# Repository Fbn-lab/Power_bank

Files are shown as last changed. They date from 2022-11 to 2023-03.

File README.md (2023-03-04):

(语言 language) : [CN](https://github.com/fBn0523/Power_bank/blob/main/README.md)|[EN](https://github.com/fBn0523/Power_bank/blob/main/README_EN.md)
# Power_bank
创意设计可乐形状的充电宝\
体积:65直径x116高(mm)\
方案: bm3451电池保护芯片+ip2368充电宝soc(5串18650带均衡)
# 参数

     快充协议:   FCP AFC SCP DPR Try.SRC PD3 QC2 QC3 QC3+(具体以手册为准)
     电压挡位:   5V 9V 12V 15V 20V
     输入:        最大60w 20V3A (双导热管)
                  最大40w 20V2A (无导热管)
     输出:         60W最大20V 3A
     充电指示灯:     (具体根据自己选用的指示灯颜色)
                          放电:                     充电:
                          白 100%~66%               充满 白
                          黄白 66%~33%              100%~66% 白闪
                          黄 小于33%                66%~33%  黄白闪
                          黄闪后结束输出 0%          33%~0%黄闪

# 特性
      1. 双铜管散热
      2. 保护板控制板叠层设计紧凑内部空间
      3. 可拆卸锂电池仓.方便更换电芯
      4. 60W快充,平衡容量和充电速度.1时20分即可充满
# 制造可行性

      1. 所有零件均可以使用fdm  3d打印制造
      2. 优化电路板减少手工焊接短路风险
      3. 开源文件包含pcb焊接示意图,方便查看每个零件需要焊接的位置
      4. 使用5节亿纬锂能3300mah 18650电芯.整体造价100(人民币)左右
      5. 外壳需要使用两个330ml可口可乐罐,切割工具需自备
# 图片
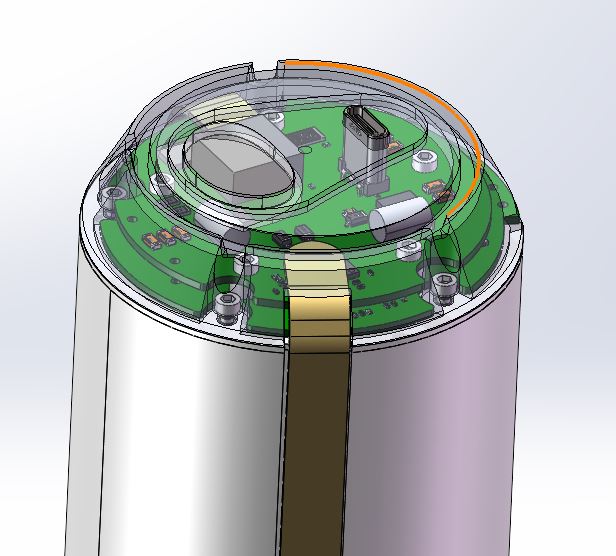
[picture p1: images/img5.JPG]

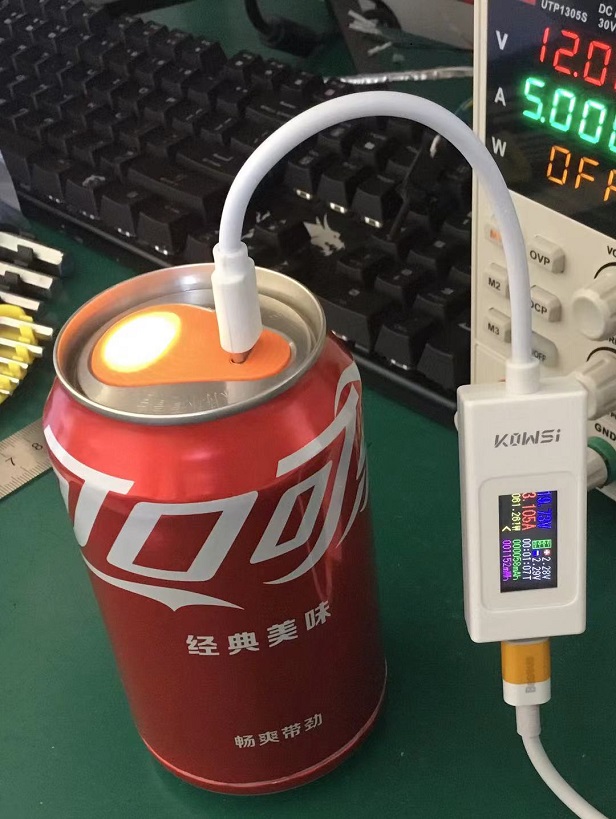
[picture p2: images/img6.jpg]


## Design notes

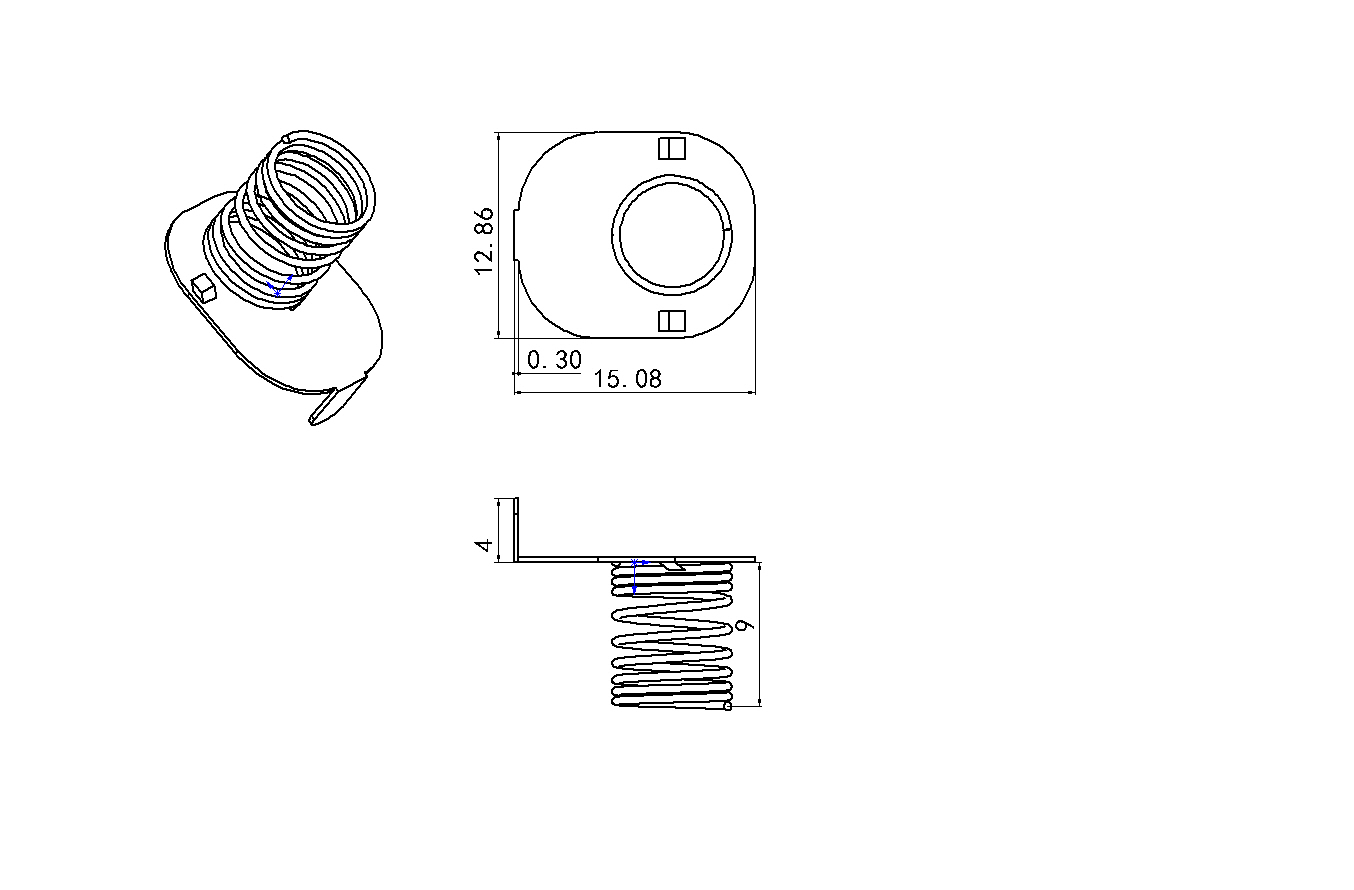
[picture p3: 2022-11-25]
images/18650电极片负极_弹簧.JPG

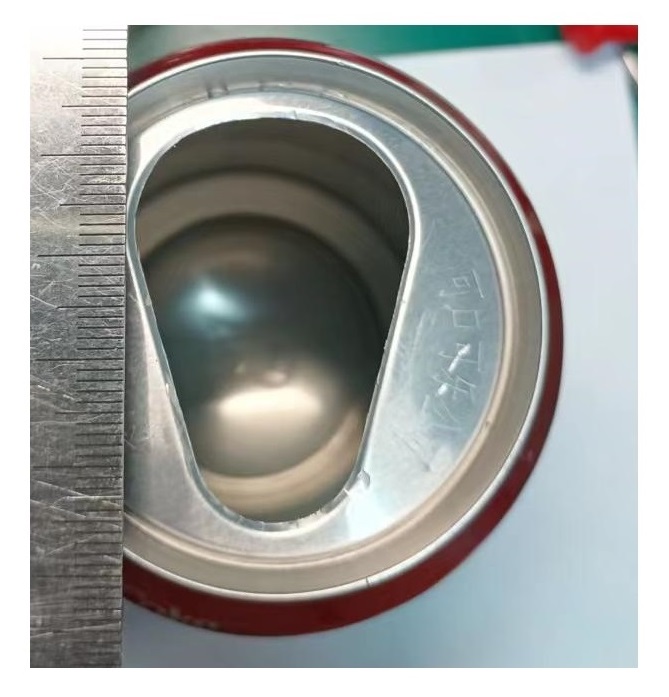
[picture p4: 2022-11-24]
images/切割示意图.jpg

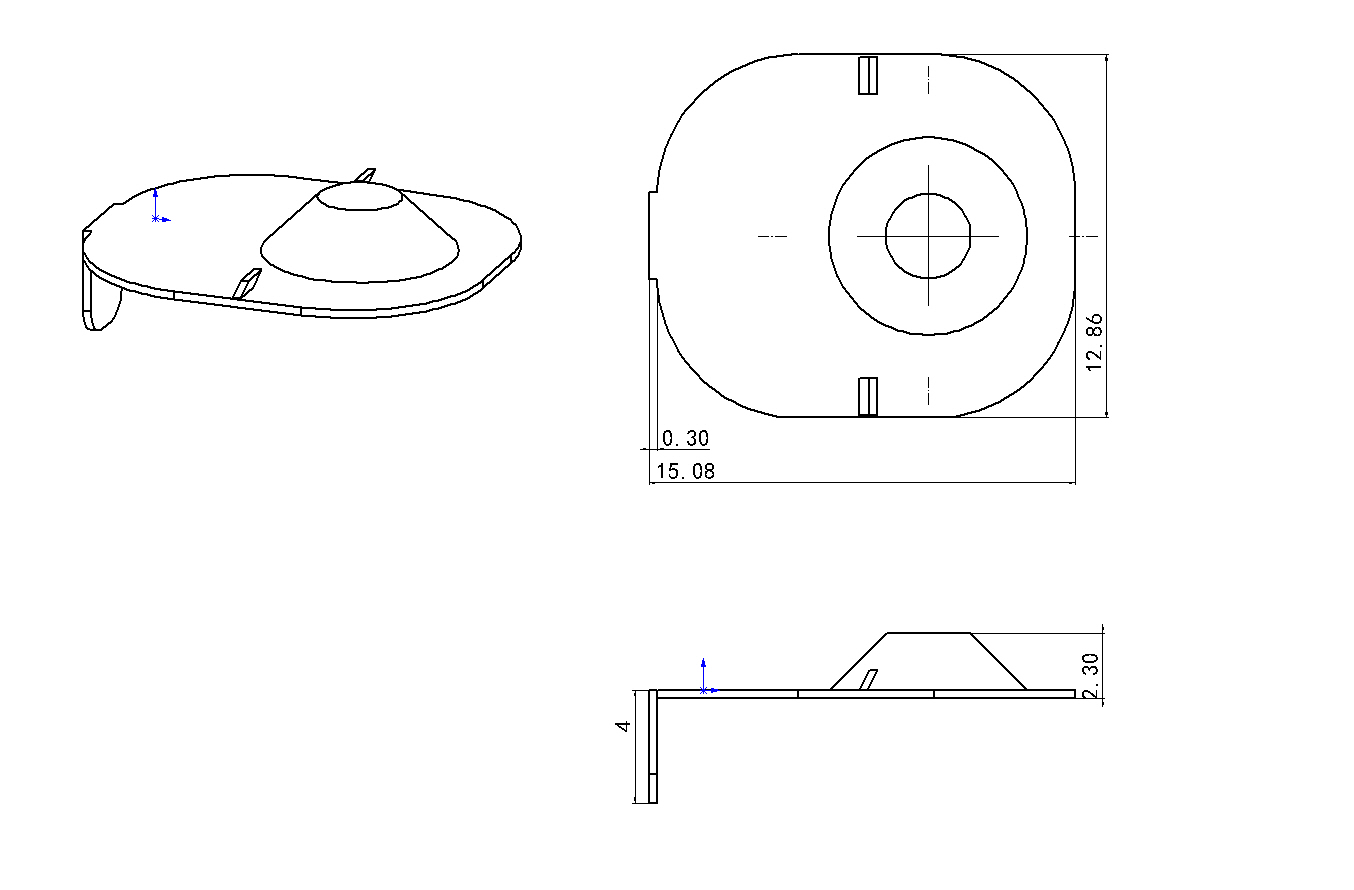
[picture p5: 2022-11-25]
images/18650电极片正极_凸点.JPG

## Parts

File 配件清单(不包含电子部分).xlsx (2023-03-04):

名称 | 数量
M2x5杯头内六角螺丝 | 13
M2x8杯头内六角螺丝 | 5
M3x5杯头内六角螺丝 | 5
热熔铜螺母M2x3x3.2 | 18 | 高度3~5mm均可.越长越结实
热熔铜螺母M3x3x4.2 | 5
电极片负极 | 5 | 详细参数见\Power_bank\images
电极片正极 | 5 | 详细参数见\Power_bank\images
导热垫片10x10x1.5 | 1
导热管 | 2 | 宽9 长8 厚1(mm)
铜片 | 1 | 长15 宽 5 厚0.3 (mm)

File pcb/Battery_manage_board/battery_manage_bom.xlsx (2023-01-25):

Comment | Description | Designator | Footprint | Quantity
BATTERY_18650- | 18650电池片 | B2, B4, B6, B8, B10 | BATTERY_18650- | 5
10uF | 无极性电容 | C1 | 0805C | 1
1uF | 无极性电容 | C2, C3, C4, C9, C10 | 0402C | 5
100nF | 无极性电容 | C5, C6, C7, C8 | 0402C | 4
NTC_100K_B3950 | 无极性电容 | C11 | 1210C | 1
BM3451TJDC | 电池管理芯片 | IC1 | SOP65P640X120-28N | 1
2302 | MOSFET (N-Channel) | Q1, Q2, Q3, Q4, Q5 | SOT95P280X125-3N | 5
KNY3403 | MOSFET (N-Channel) | Q6, Q7 | DFN5x6 | 2
1K | 电阻 | R1, R2, R5, R10, R13, R20 | 0402R | 6
47R | 电阻 | R3, R6, R11, R15, R22 | 1812R | 5
4.7MR | 电阻 | R4, R8, R12, R19, R23 | 0402R | 5
1MR | 电阻 | R7, R9 | 0402R | 2
92K | 电阻 | R14 | 0402R | 1
220K | 电阻 | R16 | 0402R | 1
2K | 电阻 | R17 | 0402R | 1
10MR | 电阻 | R18, R24 | 0805R | 2
5mR | 合金检流电阻 | R21 | 2512R | 1

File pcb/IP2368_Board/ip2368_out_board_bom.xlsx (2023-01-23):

Comment | Description | Designator | Footprint | Quantity
22uF/25V | 无极性电容 | C1, C11, C12, C13, C15, C16, C17 | 1206C | 7 | C12891
1uF/25V | 无极性电容 | C2, C6, C7, C20 | 0402C | 4
10uF/50V | 无极性电容 | C3 | 0805C | 1
2.2uF/16V | 无极性电容 | C4, C5 | 0402C | 2
100nF/50V | 无极性电容 | C8, C9, C10, C18 | 0402C | 4
100uF/25V | 固态电解电容 | C14, C19 | SMD_2x5x8 | 2 | 直径5长度8,引脚间距2(mm)
LED | 双色LED(金/白) | D1 | SMD2835 | 1
SMAJ30CAYK | TVS二极管 30V | D5, D6, D7 | SOD-123 | 3
IP2368 |  | IC2 | QFN50P700X700X90-49N-D | 1
10uH | 功率电感 | L1 | SMD_12x12x6(长宽高) | 1 | C526024
RU30J30M | 双 NMOS(半桥) | Q1, Q2 | PDFN5x6 | 2 | C2803361
KNY3403 | MOSFET (N-Channel) | Q3 | DFN5x6 | 1 | C2839428
2K | 电阻 | R1, R7 | 0402R | 2
100R | 电阻 | R2, R3 | 0402R | 2
10K | 电阻 | R4, R6 | 0402R | 2
15K | 电阻 | R5 | 0402R | 1
18K | 电阻 | R8 | 0402R | 1
10R | 电阻 | R9, R10 | 0402R | 2
0.01R | 电阻 | R11, R13 | 1206R | 2
0.005R | 电阻 | R12 | 2512R | 1
2R | 电阻 | R14, R15 | 0402R | 2
1K | 电阻 | R16 | 0402R | 1
USB_C | 连接器 | U1 | USB-C 立贴 | 1 | 14PIN 立贴 立创商品编号C2843970

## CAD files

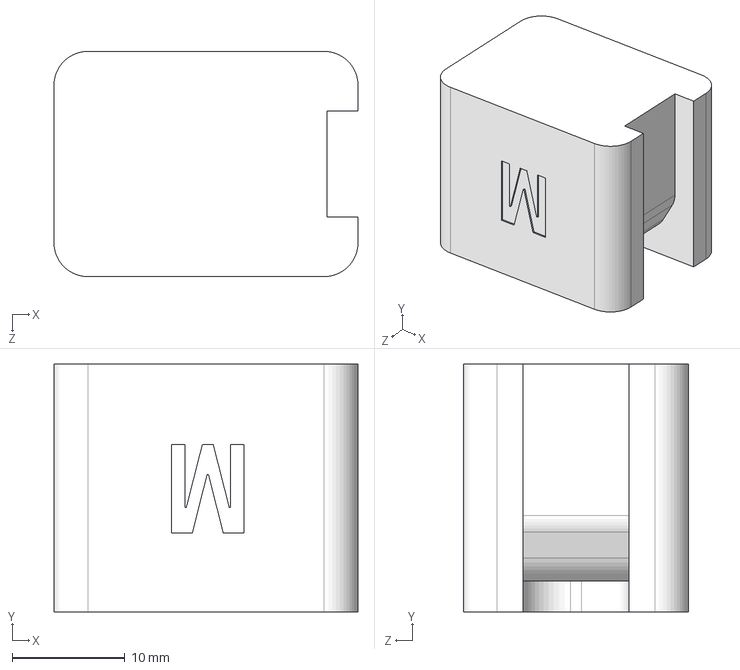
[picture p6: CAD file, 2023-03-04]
model/STEP/mos铜管模具.STEP
27.0 x 22.0 x 20.0 mm

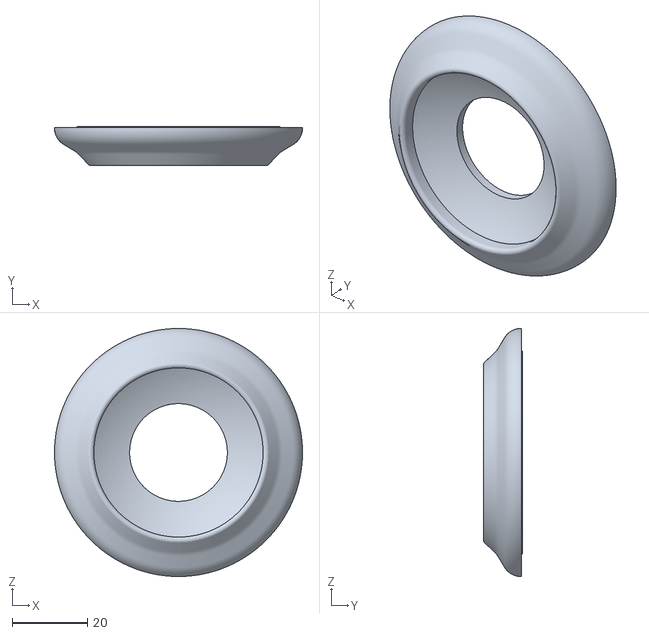
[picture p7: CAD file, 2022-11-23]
model/STL/可乐罐底支架_百事可乐.STL
66.0 x 10.4 x 66.0

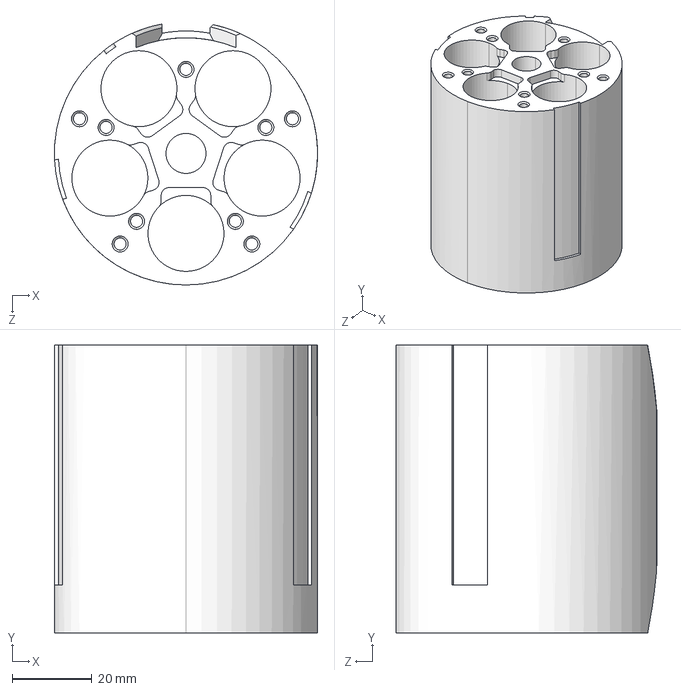
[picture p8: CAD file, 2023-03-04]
model/STEP/电池仓主体.STEP
65.8 x 72.0 x 65.2 mm

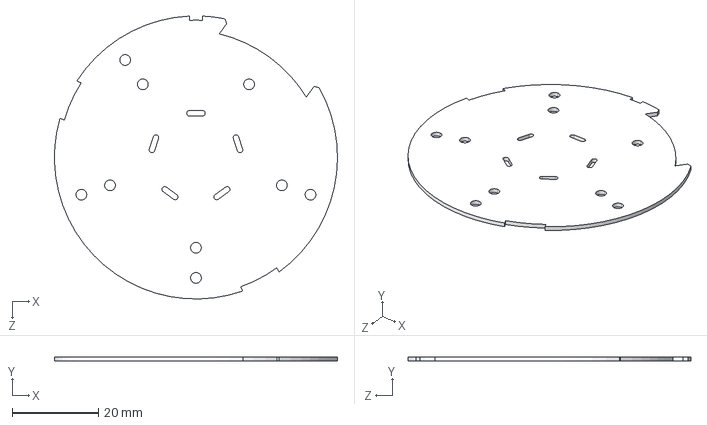
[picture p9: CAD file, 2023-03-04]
model/STEP/电池仓保护板_隔离板.STEP
65.8 x 1.00 x 65.8 mm

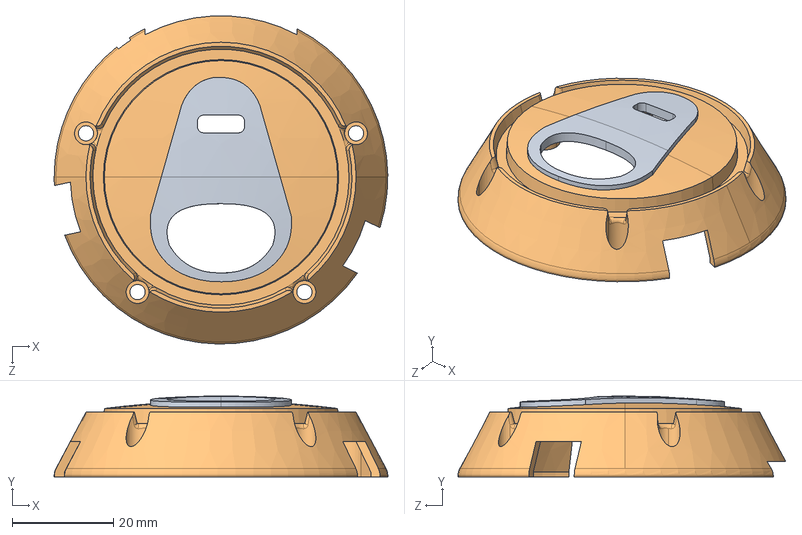
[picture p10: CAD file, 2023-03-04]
model/STEP/电池仓上盖.STEP
65.8 x 16.0 x 64.7 mm

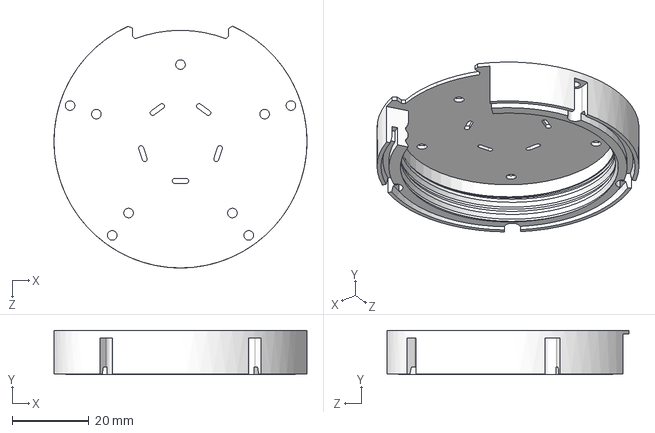
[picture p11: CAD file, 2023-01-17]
model/STEP/电池仓下盖.STEP
65.8 x 11.5 x 62.9 mm

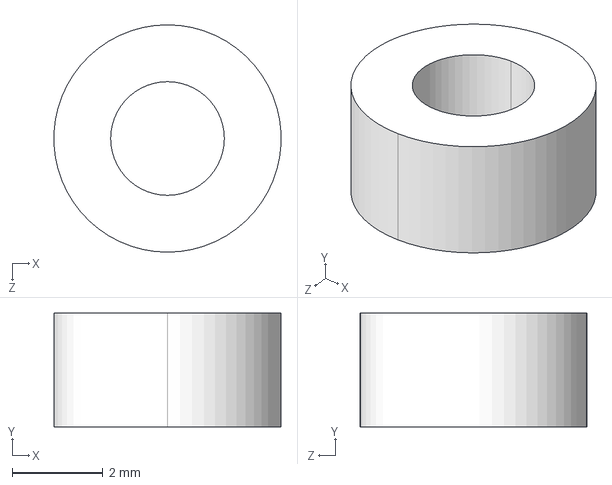
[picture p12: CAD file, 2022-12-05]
model/STEP/保护板_充电板支架.STEP
4.99 x 2.50 x 5.00 mm

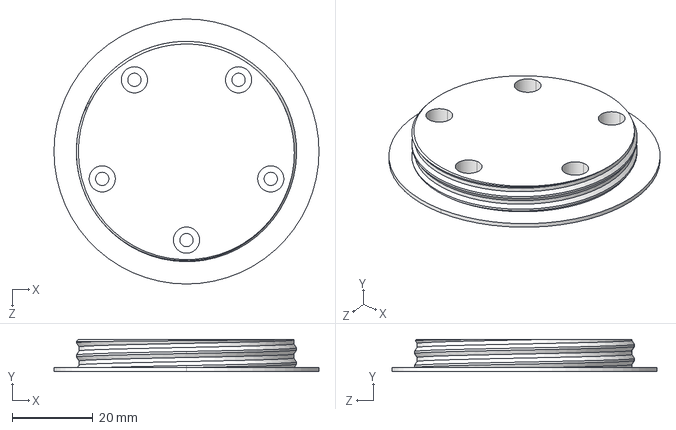
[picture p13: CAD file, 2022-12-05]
model/STEP/可乐罐支架上罐体压合_凸螺纹.STEP
65.8 x 8.00 x 65.8 mm

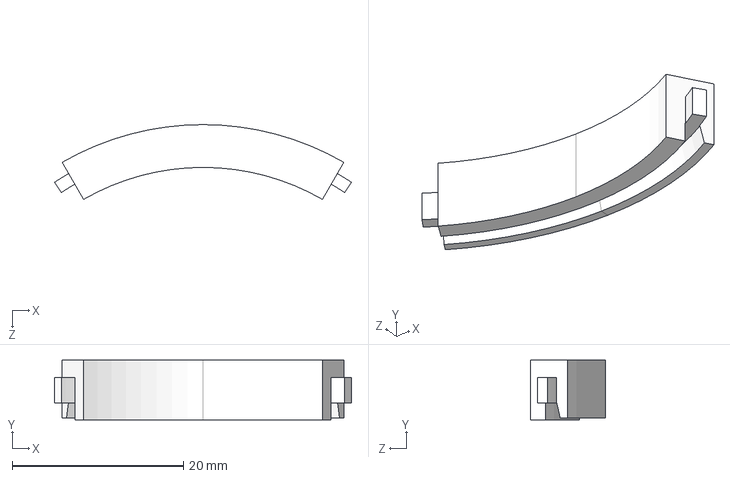
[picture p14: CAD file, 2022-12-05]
model/STEP/电池仓下盖缺口补充.STEP
34.7 x 7.00 x 8.74 mm

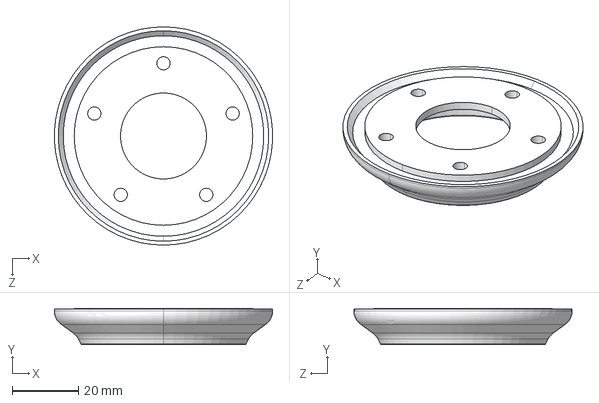
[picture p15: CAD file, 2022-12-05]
model/STEP/可乐罐底支架_可口可乐.STEP
65.9 x 10.9 x 66.0 mm

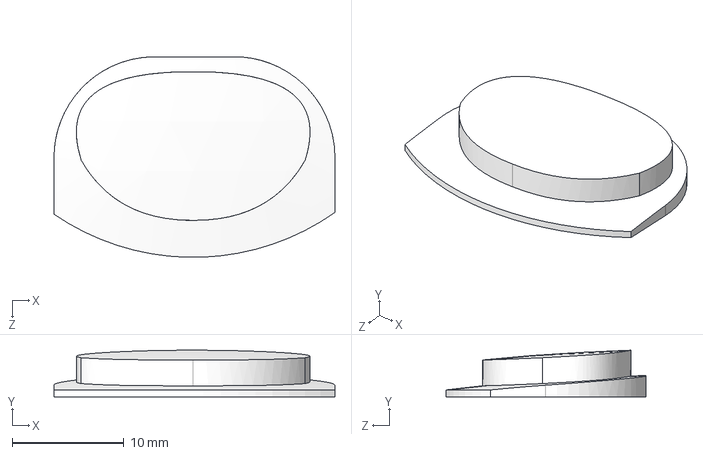
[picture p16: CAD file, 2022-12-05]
model/STEP/充电板指示灯.STEP
25.1 x 4.17 x 17.9 mm

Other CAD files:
model/STEP/soc铜管模具.STEP
model/STL/mos铜管模具.STL
model/STL/soc铜管模具.STL
model/STL/保护板_充电板支架.STL
model/STL/充电板指示灯.STL
model/STL/可乐罐底支架_可口可乐.STL
model/STL/可乐罐支架上罐体压合_凸螺纹.STL
model/STL/电池仓上盖.STL
model/STL/电池仓下盖.STL
model/STL/电池仓下盖缺口补充.STL
model/STL/电池仓主体.STL
model/STL/电池仓保护板_隔离板.STL

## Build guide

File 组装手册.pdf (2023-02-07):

# 充电宝制造教程

目录:

1: 3D 打印注意事项
2: pcb 制造注意事项
3:组装步骤:
3.1:电池仓主体热熔螺母安装
3.2:保护板电极片焊接
3.3:上半部分总成
3.4:热敏电阻安装
3.5:底部支架热熔螺母安装

## 3.6:支架总成

3.7:正极电极片焊接
3.8:电池仓总成
3.9:指示灯安装

## 4.0:上盖总成

4:导热管安装:

## 4.1 mos 导热管弯管 4.2 soc 导热管弯管

5 外壳切割:

## 5.0:罐 A 下底切割 5.1:罐 B 下底切割 5.2:罐 B 上切口

6:建议
附录:

## 1.pcb 配件表 2.pcb 焊接指导

3.机械配件表

## 1: 3D 打印制造事项

## 模型目录(\Power_bank\model\STL)

建议印刷材料 ABS 0.4 喷嘴 壁厚 4 ,层高 0.12, 顶底 5

## 模型:(有条件的都上防火材料吧)

电池仓主体x1 | 务必 ABS!! 耐热 70 度!!热敏电阻开口,底部斜边加支撑
电池仓下盖 x1
电池仓下盖缺口补充 x1
电池仓上盖 x1 | 盖口向下打印,风冷开满
充电板指示灯 x1 | 透光白色
保护板充电板支架 x5 | 务必 ABS(否则模型塌陷导致 pcb 短路)
电池仓保护板_隔离板 x1 | 可以选择激光切割或者 pcb 方式加工硬质板材
可乐罐底支架_可口可乐(可选百事可乐)x1
可乐罐支架上罐体压合_凸螺纹 x1

## 弯管模具 mos x1 弯管模具 soc x1

## 2: pcb 制造注意事项

充电电流设置电阻(R15) 建议 2K(2A) 兼顾快充和电池寿命 建议充放电控制板和电池保护板之间贴导热垫

## 3: 组装步骤:

3.1 电池仓主体热熔螺母安装
1. 电池仓主体.STL | x1
2. 2.热熔螺母 M2 (长度 3~5) | x18

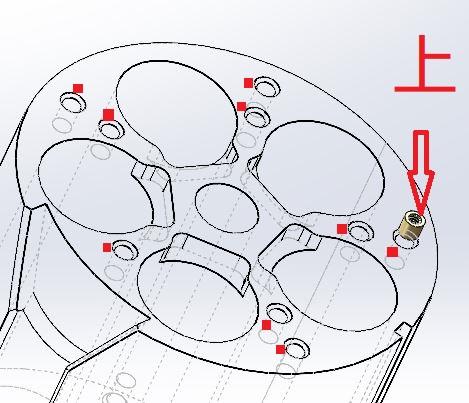
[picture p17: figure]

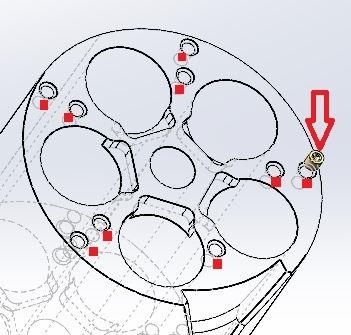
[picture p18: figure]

3.2 保护板电极片焊接

## Pcb(Battery_manage_board) x1

电池仓保护板_隔离板.STL | x1
18650 电极片负极_弹簧 | x5

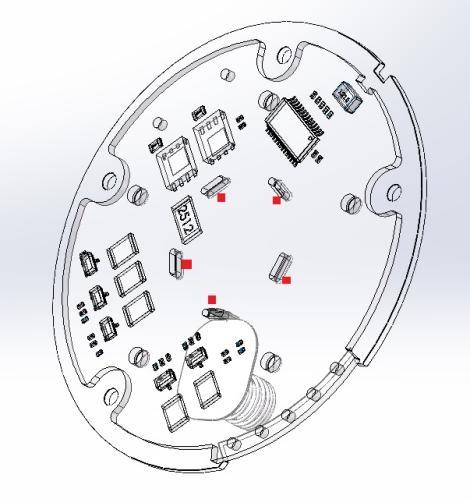
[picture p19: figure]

3.3 上半部分总成
M2x8 | x5
保护板_充电板支架.STL | x5
Pcb(IP2368_Board) | x1
导热硅胶垫 | x1

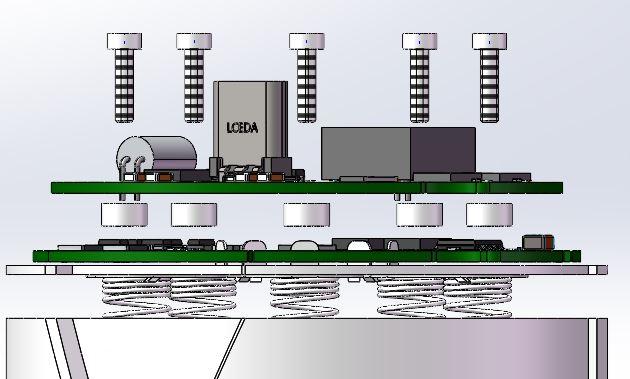
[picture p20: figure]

3.4 热敏电阻安装
NTC100K B3950 | x1

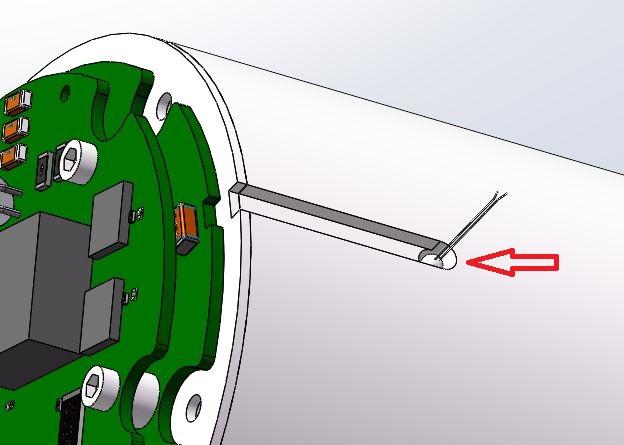
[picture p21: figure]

3.5 底部支架热熔螺母安装
可乐罐底支架_可口可乐.STL | x1
热熔螺母 M3 高 3mm | x5

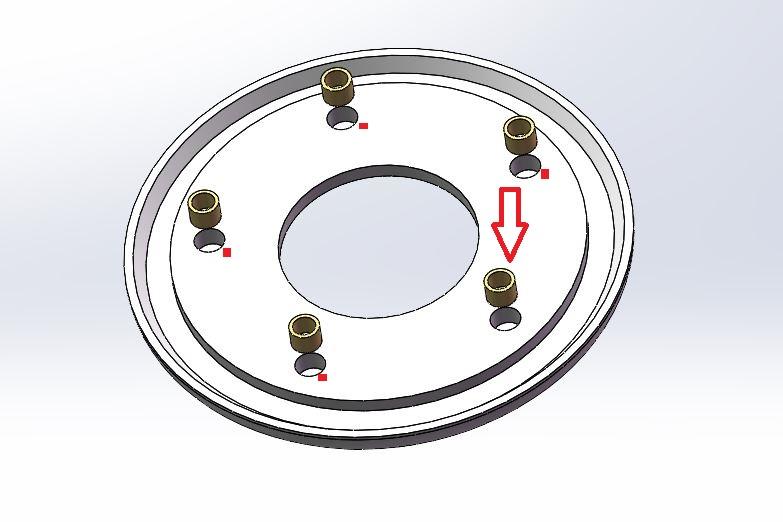
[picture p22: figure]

3.6 支架总成
可乐罐支架上罐体压合_凸螺纹.STL | x1
M3x5 | x5
可乐罐下底切割 | x1

切割底盖卡入槽中,并压紧螺纹支架

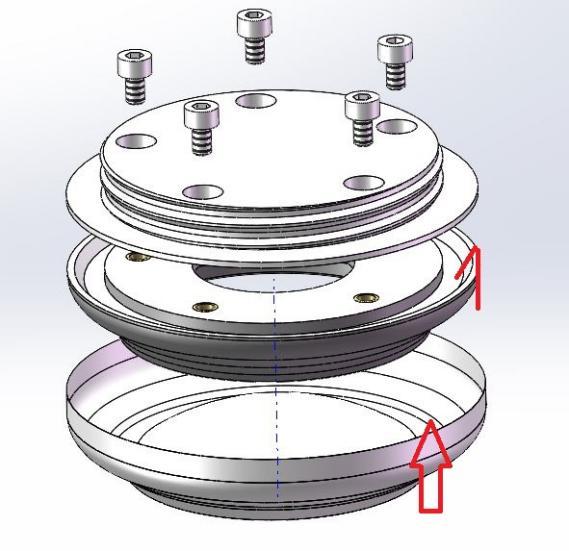
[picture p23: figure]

3.7 正极电极片焊接
电池仓下盖.STL | x1
Pcb(battery_bottom_board) | x1
18650 电极片正极_凸点 | x5

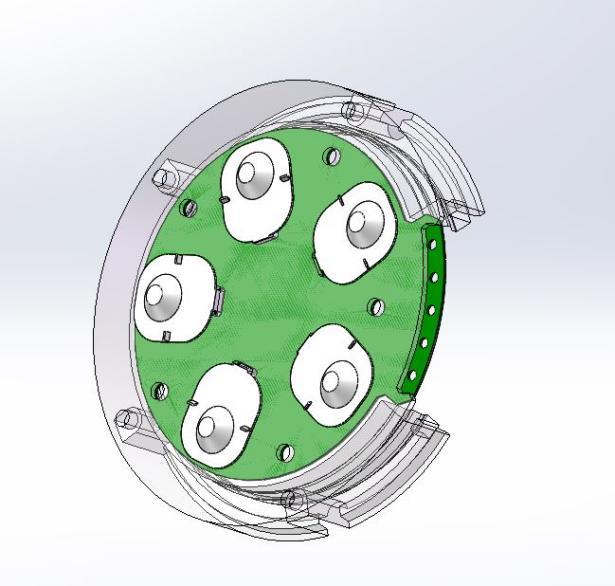
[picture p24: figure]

3.8 电池仓总成
18650 电池 | x5
M2x5 | 9

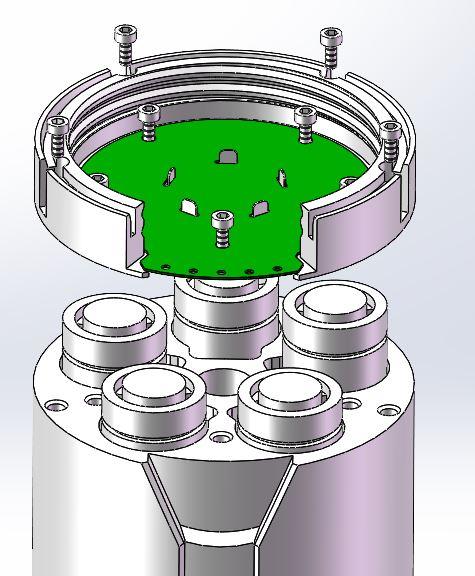
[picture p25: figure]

3.9 指示灯安装
充电板指示灯.STL | x1
电池仓上盖.STL | x1
需要胶水固定

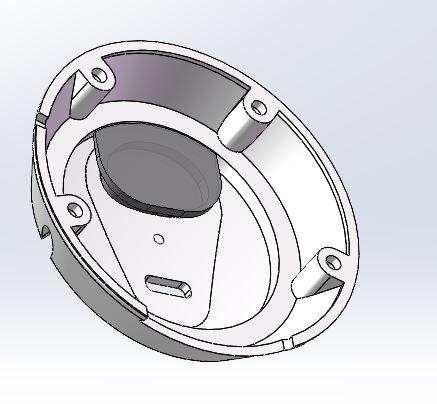
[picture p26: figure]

4.0 | 上盖总成
M2x5 | x4

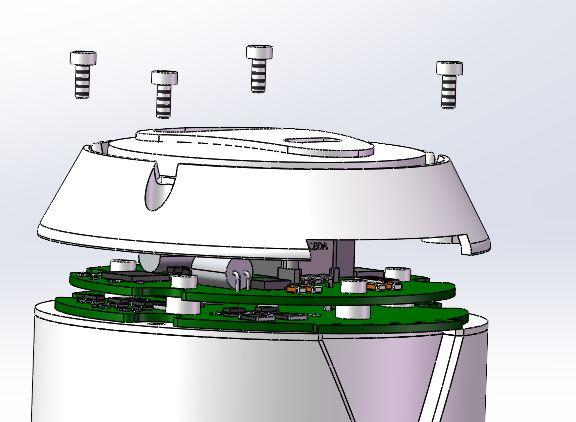
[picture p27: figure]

4: 导热管安装
材料准备
8x9x1(长宽高)(mm)导热管 | x2
弯管模具 mos | x1
弯管模具 soc | x1
导热硅脂
导热胶
4.1 mos 导热管弯管 | 4.2 soc 导热管弯管

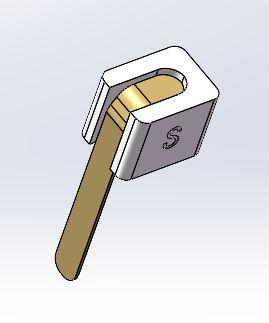
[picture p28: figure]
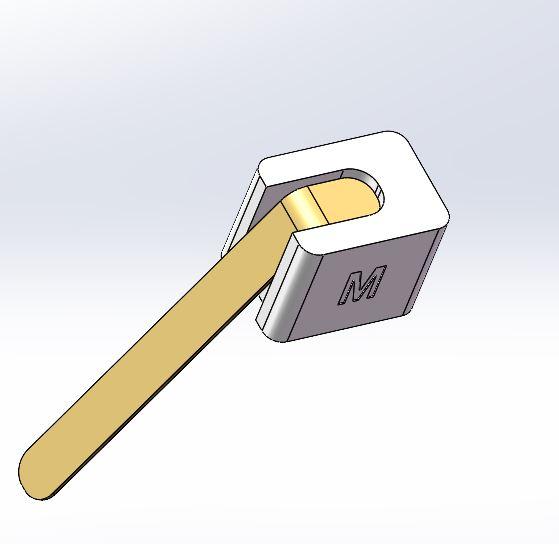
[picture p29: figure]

## 5 材料准备

可口可乐罐 | x2

5.0 罐 A 下底切割

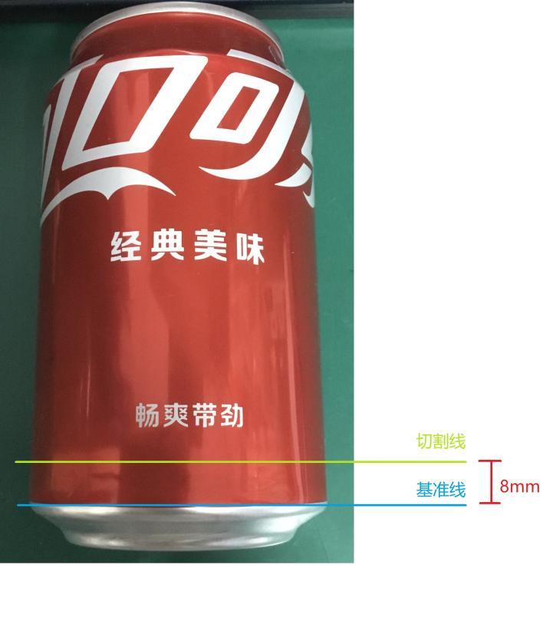
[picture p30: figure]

5.1 罐 B 下底切割

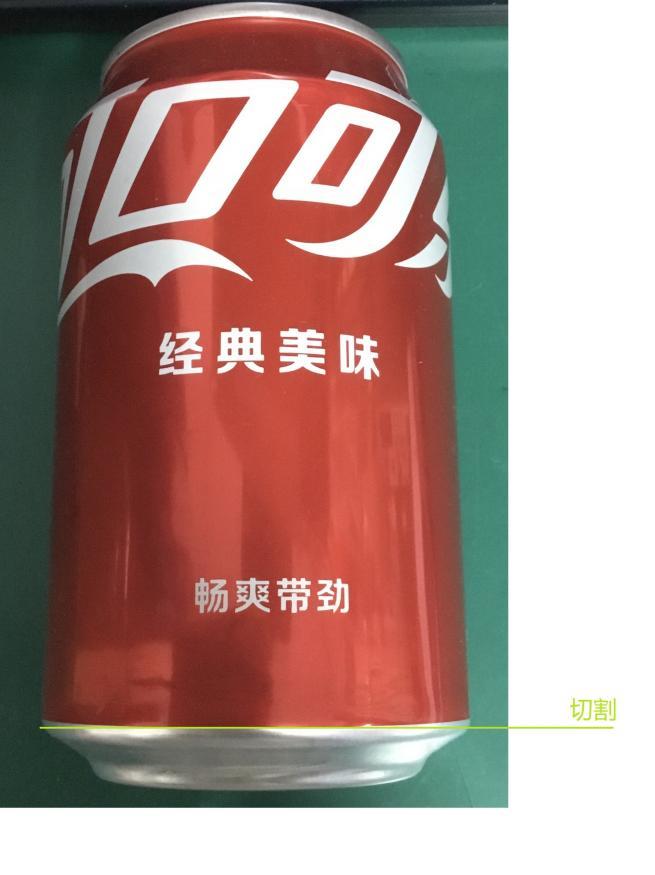
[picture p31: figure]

## 5.2 罐 B 上切口

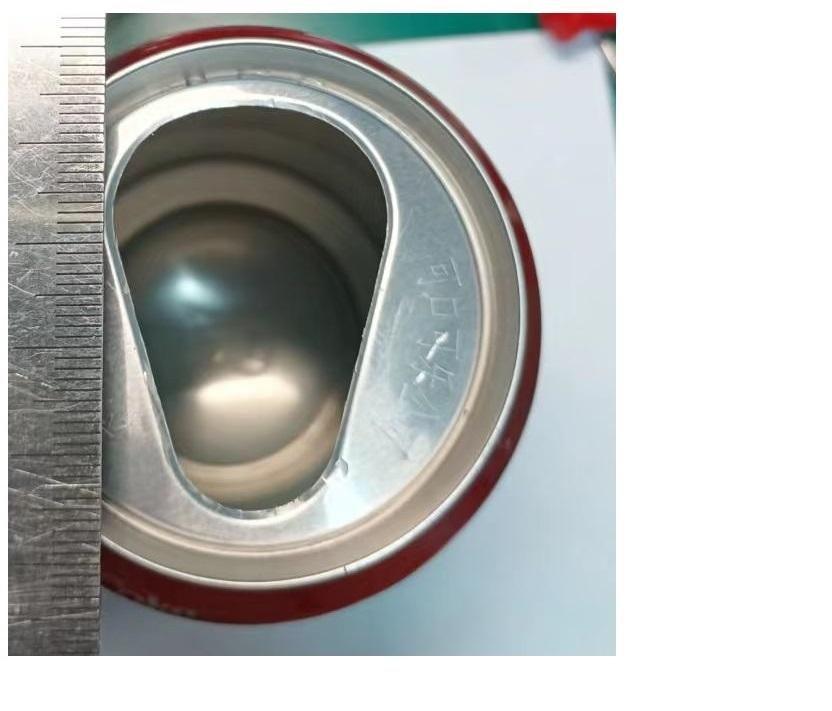
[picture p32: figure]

附录:

## 充电板(\Power_bank\pcb\IP2368_Board\IP2368_Board_bom.xlsx)

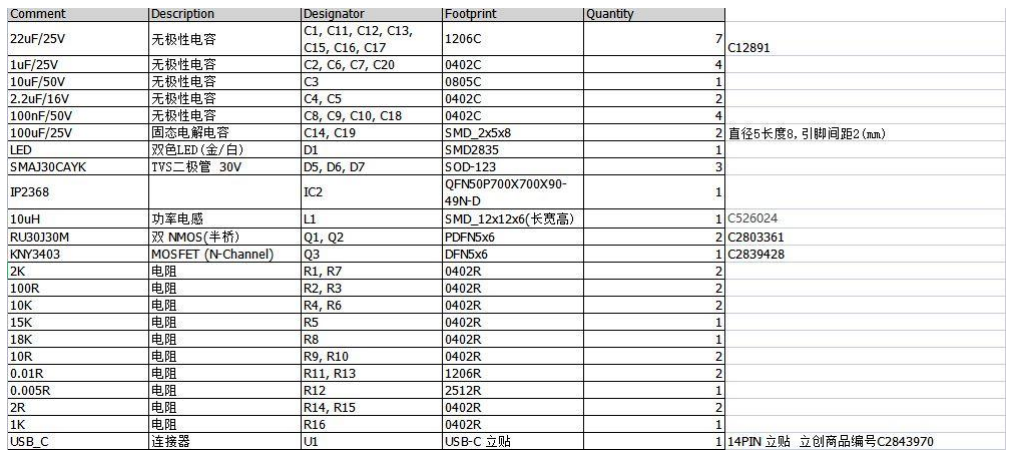
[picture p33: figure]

## pcb 焊接指导(\Power_bank\pcb\IP2368_Board\IP2368_Board_bom.html)

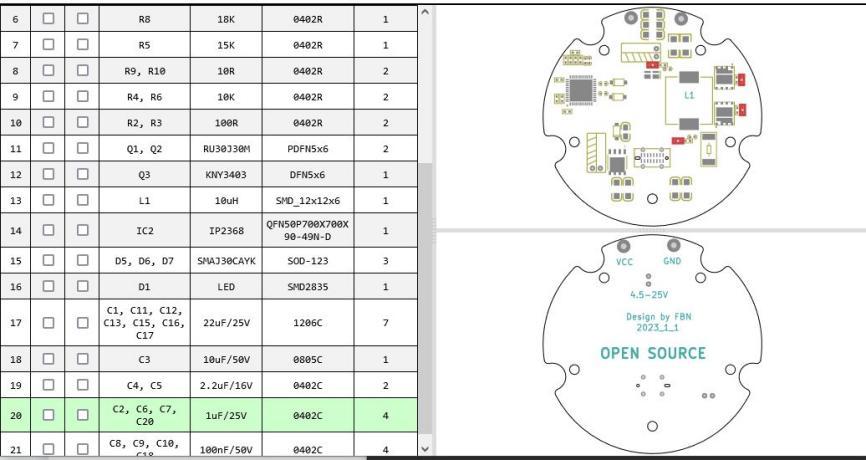
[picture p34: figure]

电池保护板

## (\Power_bank\pcb\Battery_manage_board\Battery_manage_board_bom.xlsx)

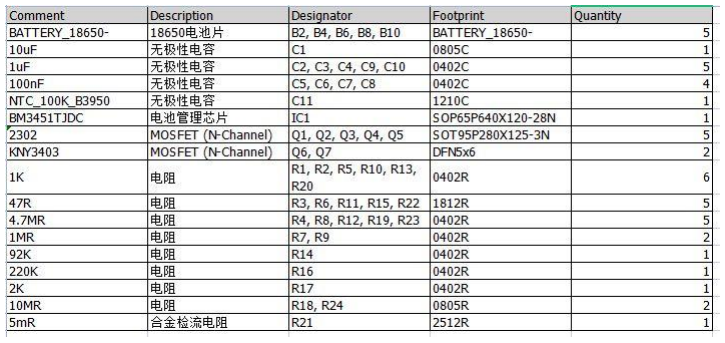
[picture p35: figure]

## pcb 焊接指(\Power_bank\pcb\Battery_manage_board\battery_manager.html)

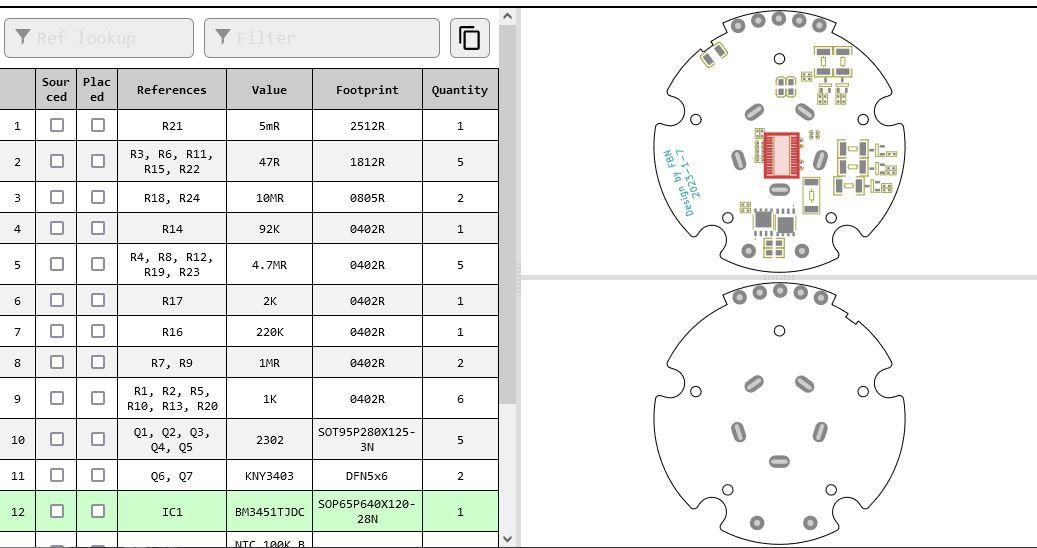
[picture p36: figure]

机械配件表(\Power_bank\配件清单(不包含电子部分))

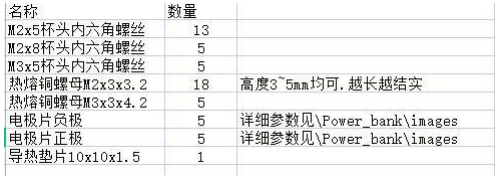
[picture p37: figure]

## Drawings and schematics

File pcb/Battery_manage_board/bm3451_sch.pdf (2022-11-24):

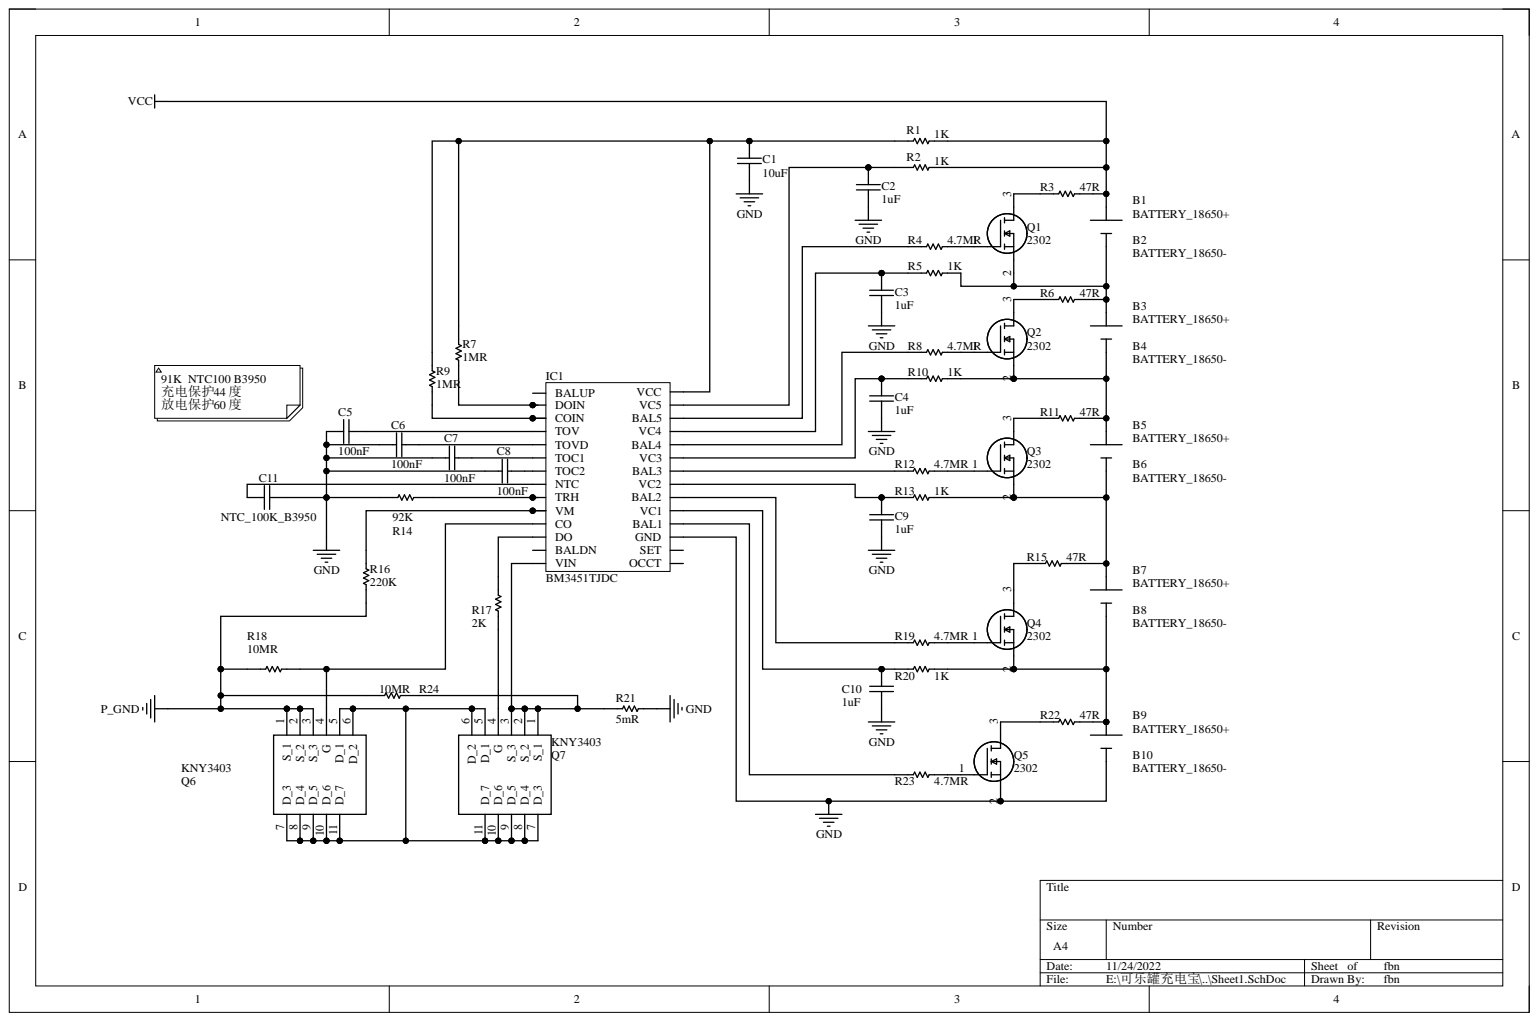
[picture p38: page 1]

GND

100nF | | C8 | GND

GND | C10

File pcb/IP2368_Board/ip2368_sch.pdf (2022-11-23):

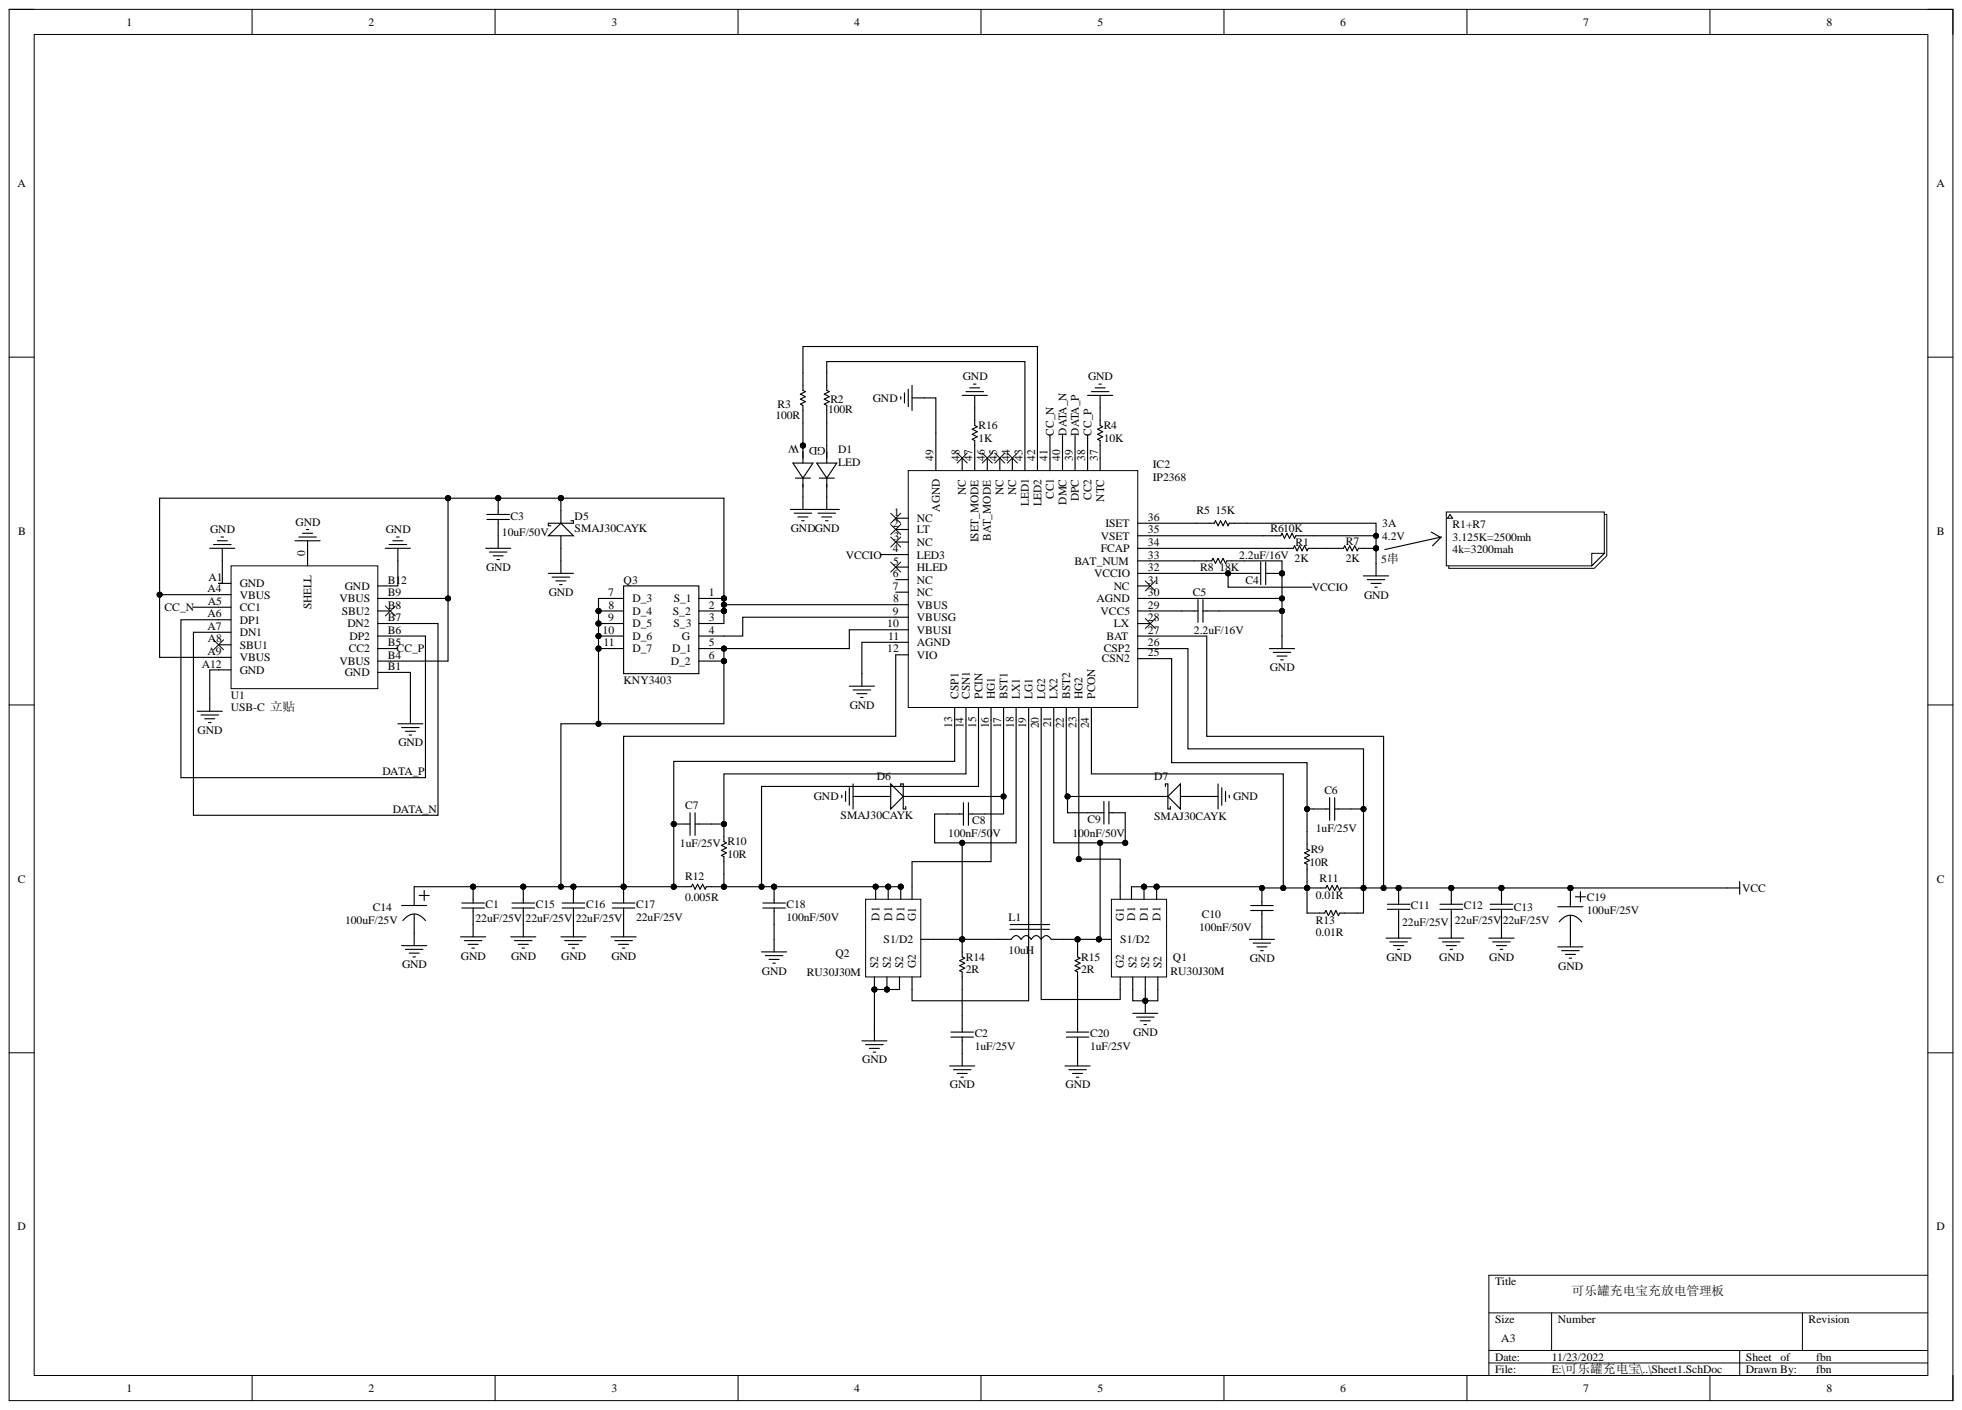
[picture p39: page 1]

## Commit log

2022-11-21 创建图片文件
2022-11-21 PCB模型
    [battery_bottom.step]
2022-11-21 增加pcb焊接指南
2022-11-21 部分模型
    [电池仓主体.STL]
2022-11-22 底部模型
    [保护板_充电板支架.STL, 可乐罐底支架_可口可乐.STL, 可乐罐支架上罐体压合_凸螺纹.STL]
2022-11-23 底部支架
    [可乐罐底支架_百事可乐.STL]
2022-11-23 放电板原理图+pcb_gerber
2022-11-23 增加电池仓下电路板
    [battery_bottom.step]
2022-11-23 全部STL模型
    [充电板指示灯.STL, 电池仓上盖.STL, 电池仓下盖.STL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]
2022-11-24 增加电池保护板原理图和pcb_gerber
2022-11-24 成品图片
2022-11-24 增加切割示意图
2022-11-25 组装手册
    [battery_bottom.step]
2022-11-25 配件清单
    [配件清单(不包含电子部分).xlsx]
2022-11-25 电极片尺寸图
2022-11-25 增加导热垫
    [配件清单(不包含电子部分).xlsx]
2022-11-27 修改大小
2022-12-05 全部STEP模型
    [保护板_充电板支架.STEP, 充电板指示灯.STEP, 可乐罐底支架_可口可乐.STEP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]
2022-12-05 补充元器件
    [ip2368_out_board.xlsx]
2022-12-21 加入热熔螺母
    [配件清单(不包含电子部分).xlsx]
2022-12-21 电阻->连接器
    [ip2368_out_board.xlsx]
2022-12-21 导线槽加深1mm
    [电池仓下盖.STEP, 电池仓主体.STEP, 电池仓保护板_隔离板.STEP]
2022-12-21 倒角热熔螺母孔
    [电池仓主体.STL]
2022-12-21 加深导线槽1mm
    [电池仓下盖.STL, 电池仓保护板_隔离板.STL]
2022-12-21 新增步骤3
2022-12-28 补充下盖安装,上盖灯板安装
2022-12-31 散热器图片
2023-01-10 优化电路板
2023-01-10 配合导热铜管,模型开槽
    [电池仓上盖.STEP, 电池仓上盖.STL, 电池仓主体.STEP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]
2023-01-10 更新pcb装配表
2023-01-10 删除旧的
2023-01-10 新pcb装配表
2023-01-10 推荐使用防火材料
2023-01-17 添加pcb源文件(包含集成库,外形图)
2023-01-17 更换热敏电阻位置_优化导线槽
    [电池仓上盖.STEP, 电池仓上盖.STL, 电池仓下盖.STEP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]
2023-01-19 加入工程源文件,修改装配表,修改Gerber文件
2023-01-19 修改装配表(采用电阻外围)
2023-01-19 加入电池管理板工程源文件
2023-01-19 加入电池管理板源文件
2023-01-22 修改LICENSE
2023-01-22 更详细的解释
2023-01-23 加入部分零件立创商城商品号
    [ip2368_out_board.xlsx]
2023-01-23 完善附录
2023-01-25 新加入_保护板配件表
    [battery_manage_bom.xlsx]
2023-02-04 加入导热铜管
    [配件清单(不包含电子部分).xlsx]
2023-02-06 增加切割罐示意图
2023-02-07 弯管模具
    [mos铜管模具.STEP, mos铜管模具.STL, soc铜管模具.STEP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]
2023-02-07 补充弯管示意图
2023-02-08 充电板焊接指南
2023-03-04 添加图片
2023-05-04 更新电池保护芯片链接
